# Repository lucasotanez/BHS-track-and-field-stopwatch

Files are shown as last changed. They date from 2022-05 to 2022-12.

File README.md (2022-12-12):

# track-and-field-stopwatch

Arduino code for the jumbo stopwatch I made for my high school's track and field team to use during meets. This jumbo stopwatch replaced the handheld
stopwatch that was being used prior. This new jumbo stopwatch allows the crowd to view a runner's time from anywhere in the stands. The stopwatch also utilizes
a foot pressure sensor and a laser sensor for starting and stopping the runner's time.

## materials

- 6 7-segment displays (6.5 inch) https://www.sparkfun.com/products/8530 
- 6 large digit drivers https://www.sparkfun.com/products/13279
- Arduino UNO or SparkFun Redboard https://www.sparkfun.com/products/13975
- breadboard (optional)
- jumper wires, resistors, LEDs
- assorted M4 screws
- a box or frame to mount the displays
- 12V power supply
- 2 push buttons (any style)
- *optional* foot pressure pad sensor and laser trip sensor

## instructions

- lasercut using the included CAD files or manually cut a box for the displays
- assemble box/container for the displays and hardware - use machine screws as needed - reference images
- daisy chain and solder the large digit drivers for all 6 displays (see image)
- connect all wires to the correct GPIO pins on the board, driver, and breadboard using the pinout diagram
- upload the Arduino code file 'trackTimer.ino' to the board
- finally, test all buttons and sensors and make sure all is working properly (see video for demonstrations)

demo:

https://user-images.githubusercontent.com/72469916/171058819-89fa432c-c79e-4eef-baa5-21803a410552.mp4

wiring diagram:

trackAndFieldWiringDiagram

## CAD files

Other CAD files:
CAD/TimerFront.dxf

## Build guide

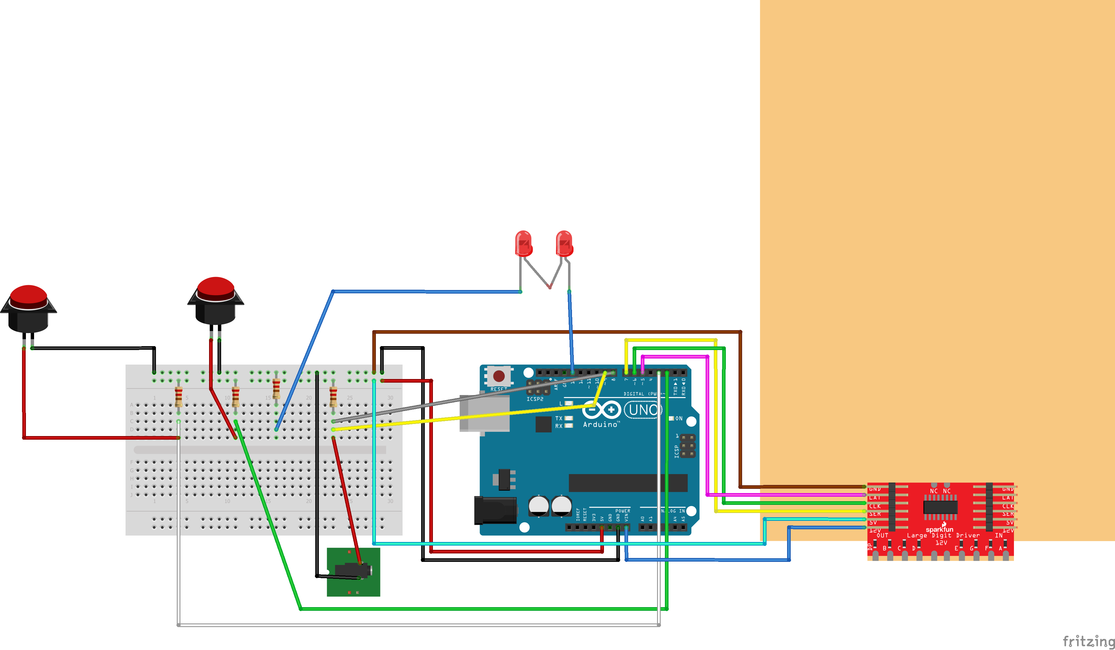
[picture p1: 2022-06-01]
trackAndFieldWiringDiagram.png

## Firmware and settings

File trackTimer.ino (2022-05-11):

/*
 * Code adapted from "testSingleDigit" by Nathan Seidle 
 * of Sparkfun Electronics (2015).
 * By: Lucas Otanez
 * Date: May 11th, 2022
 */

#include <stdio.h>
#include <math.h>
#include <string.h>
#include <stdbool.h>

//GPIO declarations
//-=-=-=-=-=-=-=-=-=-=-=-=-=-=-=-=-=-=-=-=-=-=-=-=
byte segmentClock = 6;
byte segmentLatch = 5;
byte segmentData = 7;

byte greenButton = 2;
byte whiteButton = 3;
int greenButtonState;
int whiteButtonState;
int laserState;
int modeStatus;

byte timeData = 8;
byte modeIn = 9;

//-=-=-=-=-=-=-=-=-=-=-=-=-=-=-=-=-=-=-=-=-=-=-=-=

void setup()
{
  Serial.begin(9600);
  Serial.println("Large Digit Driver Example");

  pinMode(segmentClock, OUTPUT);
  pinMode(segmentData, OUTPUT);
  pinMode(segmentLatch, OUTPUT);

  pinMode(greenButton, INPUT);
  pinMode(whiteButton, INPUT);

  pinMode(timeData, INPUT);
  pinMode(modeIn, INPUT);

  pinMode(13, OUTPUT);

  digitalWrite(segmentClock, LOW);
  digitalWrite(segmentData, LOW);
  digitalWrite(segmentLatch, LOW);

}

//variable declarations
//-=-=-=-=-=-=-=-=-=-=-=-=-=-=-=-=-=-=-=-=-=-=-=-=
int seconds = 0;
float timeS;
float timeStart = millis();
int x = 0;
int milliseconds = 0;

int tenSeconds = 0;
int minutes = 0;
int tenMinutes = 0;

char* state = 'pause';

char* mode = 'buttonMode';
float modeCooldown;

bool greenButtonPressed = false;
bool whiteButtonPressed = false;

bool laserStep = false;

float runTime;
bool reset = true;

float resetMillis;
float laserResetMillis;

//-=-=-=-=-=-=-=-=-=-=-=-=-=-=-=-=-=-=-=-=-=-=-=-=

void loop()
{
  digitalWrite(13, HIGH);
  if (state == 'time'){
  
    timeS = millis();
  
    float fullTime = (timeS - timeStart)/1000;
  
    //TIMER SEGMENT STARTS
  
    if (seconds >= 10)
    {
      seconds = 0;
      timeStart = millis();
      tenSeconds += 1;
    }
  
    if (fullTime <= 1.00)
    {
      milliseconds = (timeS - timeStart)/10;
    }
    
    if (milliseconds >= 99)
    {
     milliseconds = 0;
     timeStart = millis();
     seconds += 1;
    }
  
    if (tenSeconds >= 6)
    {
      minutes += 1;
      tenSeconds = 0;
    }
  
    if (minutes >= 10)
    {
      tenMinutes += 1;
      minutes = 0;
    }
  }
  //TIMER SEGMENT ENDS

  showNumber(milliseconds, seconds, tenSeconds, minutes, tenMinutes); //Test pattern
  //Serial.println(seconds); //For debugging

  greenButtonState = digitalRead(greenButton);
  whiteButtonState = digitalRead(whiteButton);

  laserState = digitalRead(timeData);
  modeStatus = digitalRead(modeIn);
  char* cooldownState = 'inactive';

  if (state == 'time' && whiteButtonPressed == false){
    if (whiteButtonState == LOW){
      state = 'pause';
      whiteButtonPressed = true;
    }
    }
  if (state == 'pause' && whiteButtonPressed == false){
    if (whiteButtonState == LOW){
      state = 'time';
      whiteButtonPressed = true;
      timeStart = millis() - (milliseconds*10);
    }
  }
  
  else if (whiteButtonPressed == true){
    if (whiteButtonState == HIGH) {
      whiteButtonPressed = false;
    }

  }

  if (state == 'pause' && greenButtonPressed == false){
    if (greenButtonState == LOW){
      state = 'time';
      restartTimer();
      greenButtonPressed = true;
      resetMillis = millis();
    }
  }
  if (state == 'time' && greenButtonPressed == false){
    if (greenButtonState == LOW){
      restartTimer();
      greenButtonPressed = true;
      resetMillis = millis();
    }
  }
  else if (greenButtonPressed == true){
    if (greenButtonState == HIGH){
      greenButtonPressed = false;
      resetMillis = millis();
    }
    if (greenButtonState == LOW);
      if (millis() - resetMillis >= 2000){
        state = 'pause';
        restartTimer();
        reset = true;
      }
  }

  //LASERMODE CONDITIONALS
  //if (mode == 'laserMode'){ <-- this code is not applicable
    if (laserStep == false && reset == false){
        if (laserState == HIGH){
          if (millis() - laserResetMillis <= 1000){
            state = 'pause';
            restartTimer();
            reset = true;
          }
          laserResetMillis = millis();
          laserStep = true;
          return;
        }
      }
    if (state == 'pause' && laserStep == false && reset == true){
      if (laserState == HIGH){ 
        state = 'time';
        restartTimer();
        laserStep = true;      
      } 
    }
    if (state == 'time' && laserStep == false && reset == true){
      if (laserState == HIGH){
        state = 'pause';
        laserStep = true;
        reset = false;
      }
    }
    
    else if (laserStep == true){
      if (laserState == LOW) {
        laserStep = false;
      }
    }
}

void restartTimer()
{
  timeStart = millis();
  milliseconds = 0;
  seconds = 0;
  tenSeconds = 0;
  minutes = 0;
  tenMinutes = 0;
}

//Takes a number and displays 5 numbers. Displays absolute value (no negatives)
void showNumber(float value, float value2, float value3, float value4, float value5)
{
  int number = abs(value); //Remove negative signs and any decimals
  int seconds = abs(value2);
  int minutes = abs(value4);
  int tenSeconds = abs(value3);
  int tenMinutes = abs(value5);
  //Serial.print("number: "); //debugging
  //Serial.println(number);

  for (byte x = 0 ; x < 2 ; x++)
  {
    int remainder = number % 10;

    postNumber(remainder, false);
    number /= 10;
  }

  for (byte x = 2 ; x < 3 ; x++)
  {
    int rem = seconds % 10;

    postNumber(rem, true);

    number /= 10;
  }

  for (byte x = 3 ; x < 4 ; x++)
  {
    int rem = tenSeconds % 10;

    postNumber(rem, false);

    number /= 10;
  }

  for (byte x = 4 ; x < 5 ; x++)
  {
    int rem = minutes % 10;

    postNumber(rem, false);

    number /= 10;
  }

  for (byte x = 5 ; x < 6 ; x++)
  {
    int rem = tenMinutes % 10;

    postNumber(rem, false);

    number /= 10;
  }

  //Latch the current segment data
  digitalWrite(segmentLatch, LOW);
  digitalWrite(segmentLatch, HIGH); //Register moves storage register on the rising edge of RCK
}

//Given a number, or '-', shifts it out to the display
void postNumber(byte number, boolean decimal)
{
  //    -  A
  //   / / F/B
  //    -  G
  //   / / E/C
  //    -. D/DP

#define a  1<<0
#define b  1<<6
#define c  1<<5
#define d  1<<4
#define e  1<<3
#define f  1<<1
#define g  1<<2
#define dp 1<<7

  byte segments;

  switch (number)
  {
    case 1: segments = b | c; break;
    case 2: segments = a | b | d | e | g; break;
    case 3: segments = a | b | c | d | g; break;
    case 4: segments = f | g | b | c; break;
    case 5: segments = a | f | g | c | d; break;
    case 6: segments = a | f | g | e | c | d; break;
    case 7: segments = a | b | c; break;
    case 8: segments = a | b | c | d | e | f | g; break;
    case 9: segments = a | b | c | d | f | g; break;
    case 0: segments = a | b | c | d | e | f; break;
    case ' ': segments = 0; break;
    case 'c': segments = g | e | d; break;
    case '-': segments = g; break;
  }

  if (decimal) segments |= dp;

  //Clock these bits out to the drivers
  for (byte x = 0 ; x < 8 ; x++) //8 digits
  {
    digitalWrite(segmentClock, LOW);
    digitalWrite(segmentData, segments & 1 << (7 - x));
    digitalWrite(segmentClock, HIGH); //Data transfers to the register on the rising edge of SRCK
  }
}
